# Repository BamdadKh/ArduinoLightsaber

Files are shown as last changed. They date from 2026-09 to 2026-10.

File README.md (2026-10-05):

# Arduino Lightsaber

A lightsaber prop built around an Arduino Nano on a custom PCB. It has a 144-LED blade,
sound from a DFPlayer Mini, swing detection with an MPU-6050, a small OLED and two buttons.
I built it for a Halloween costume.

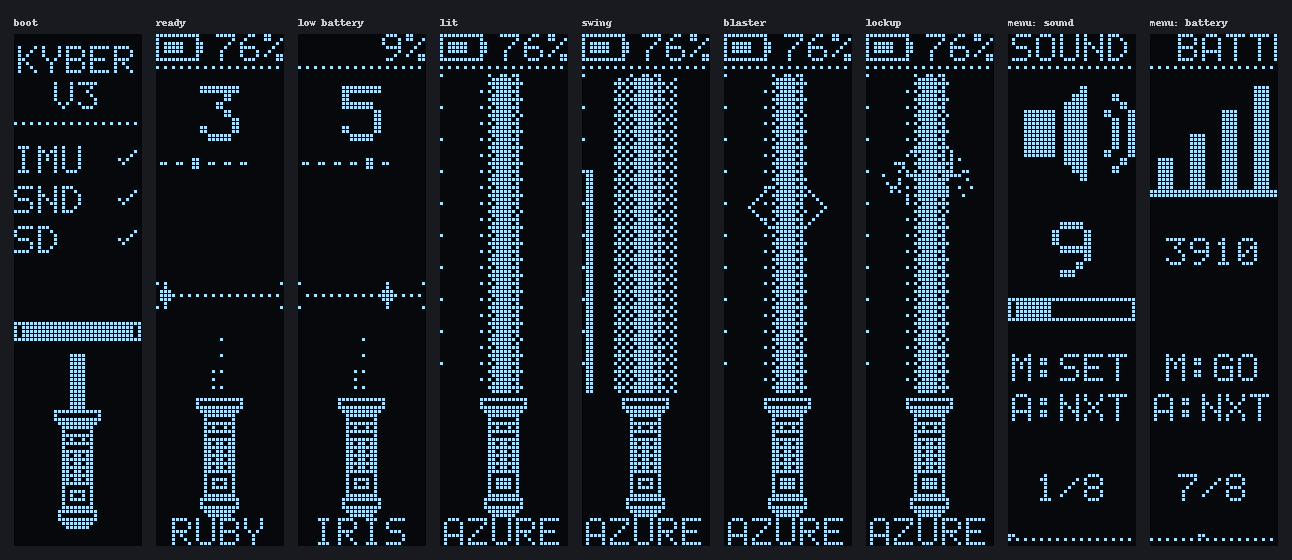
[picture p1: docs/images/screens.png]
OLED screens


*The OLED screens, rendered by the firmware's own UI code in a PC simulator.*

## Hardware

| | |
|---|---|
| Microcontroller | Arduino Nano (ATmega328P) |
| Motion | GY-521 (MPU-6050) on I²C |
| Sound | DFPlayer Mini, external amplifier and speaker |
| Blade | WS2812B strip, 144 LEDs, data on D6 |
| Buttons | main on D2, aux on D3 |
| Display | 0.91" SSD1306 128×32 OLED, software I²C on D8 (SDA) and D9 (SCL) |
| Power | one 18650 cell wired to the Nano's 5V pin, no boost converter |

The pin map, bill of materials and the known problems with the V3 board are in
[docs/hardware.md](docs/hardware.md). The schematic is in
[hardware/exports](hardware/exports/lightsaber-schematic.pdf). The schematic has mistakes the
board inherited; the firmware works around them, so trust the board and `docs/hardware.md`
over the schematic.

The hilt is modelled in Fusion 360 ([lightsaber-hilt.f3z](hardware/3d/lightsaber-hilt.f3z)),
and the printable tube is [hilt-tube.stl](hardware/3d/hilt-tube.stl), which GitHub shows in a
3D viewer.

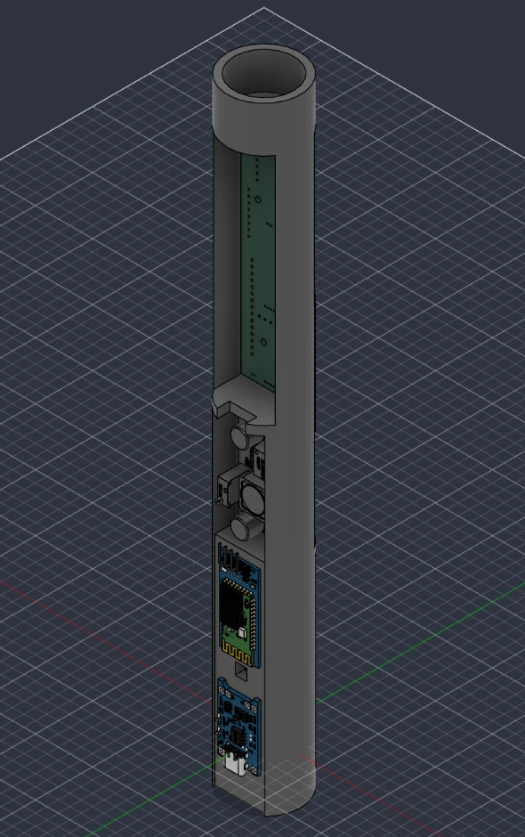
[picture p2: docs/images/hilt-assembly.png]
Hilt assembly


## Building

You need [arduino-cli](https://arduino.github.io/arduino-cli/) with the `arduino:avr` core.
The sketch has no third-party libraries.

```bash
arduino-cli compile -b arduino:avr:nano firmware/lightsaber
arduino-cli upload -b arduino:avr:nano -p COM3 firmware/lightsaber
```

Nano clones with the old bootloader need `arduino:avr:nano:cpu=atmega328old`. The build uses
about 18 KB of the 30 KB of flash and 42% of RAM. Pins, LED count, current limit and the
battery and motion thresholds are in [config.h](firmware/lightsaber/config.h).

Building with `-DDEBUG_SERIAL=1` prints swing speed and battery voltage over USB at 115200 baud:

```bash
arduino-cli compile -b arduino:avr:nano --build-property "compiler.cpp.extra_flags=-DDEBUG_SERIAL=1" firmware/lightsaber
```

### SD card

```bash
pip install numpy
python firmware/tools/build_sd_card.py
```

This fills `firmware/sd-card/` and writes `sound_lengths.h`. Copy the `MP3` and `ADVERT`
folders to the root of a FAT32 micro-SD card. Details and the track list are in
[firmware/sd-card/README.md](firmware/sd-card/README.md).

### First run

1. If the screen is upside down, flip it in the menu.
2. Lay the saber still and run CALIBRATE in the menu. This zeroes the gyro. It also happens
   at power-up if the saber is lying still.
3. Compare the BATTERY page with a multimeter on the cell. If it's off, scale `BANDGAP_MV`
   in `config.h`; the Nano's voltage reference is only accurate to about 10%.

## Controls

| Blade off | |
|---|---|
| MAIN click | Ignite |
| AUX click, double click | Next colour, previous colour |
| AUX hold | Open the menu |

| Blade on | |
|---|---|
| MAIN click | Retract |
| AUX click | Blaster block |
| AUX hold | Lockup, until released |
| Swing | Swing sound (automatic) |

| Menu | |
|---|---|
| AUX click, double click | Next page, previous page |
| MAIN click | Change the value or run the action |
| AUX hold | Save and exit |

The menu pages are sound, light, colour, sensitivity, flip, calibrate, battery and exit.
Light and colour preview on the blade. The saber retracts by itself after five minutes
without movement.

## How it works

The blade is rendered per pixel into the LED array, which is the only frame buffer in the
sketch. The OLED has none either. The panel is mounted on its side and driven in vertical
addressing mode, so one physical column is one 32-pixel row of the portrait screen. Each
screen is a function that returns a row as a `uint32_t`, and the UI streams a few rows per
`loop()` pass.

The LED strip needs interrupts off for about 4 ms per frame, which rules out serial
receive. The DFPlayer is therefore driven blind. The hum loops on the main channel,
effects play as DFPlayer adverts that pause and then resume it, and the one-shot lengths are
compiled in so the firmware can stop them when they end.

The cell feeds the Nano's supply directly, so the supply voltage is the cell voltage. The
firmware measures it against the internal 1.1 V reference. Charge level and warnings use the
voltage with the blade off, because the strip pulls it down by several tenths of a volt when lit.

| Module | Job |
|---|---|
| `saber.cpp` | modes and controls |
| `imu.cpp` | MPU-6050 reading and swing detection |
| `blade.cpp` | blade colours, ignition and effects |
| `color.cpp` | WS2812B driver, current limit |
| `ui.cpp`, `gfx.h`, `oled.cpp` | OLED screens and display driver |
| `audio.cpp` | DFPlayer protocol and sound playback |
| `buttons.cpp` | debouncing, clicks, holds |
| `power.cpp` | battery voltage |
| `settings.cpp` | EEPROM settings, colour table |

## Repository

```
firmware/lightsaber/   the sketch
firmware/sd-card/      sounds for the DFPlayer
firmware/tools/        asset and SD card builders, PC simulator
hardware/kicad/        KiCad 8 project
hardware/fabrication/  gerbers exactly as ordered (V3)
hardware/exports/      schematic PDF, PCB renders
hardware/3d/           hilt model, tube STL, PCB STEP
docs/                  hardware notes, images
```

The simulator runs the real `ui.cpp` and `blade.cpp` on a PC (it needs MSYS2 g++ or MSVC):

```bash
python firmware/tools/sim/run_sim.py
python firmware/tools/make_readme_images.py
```

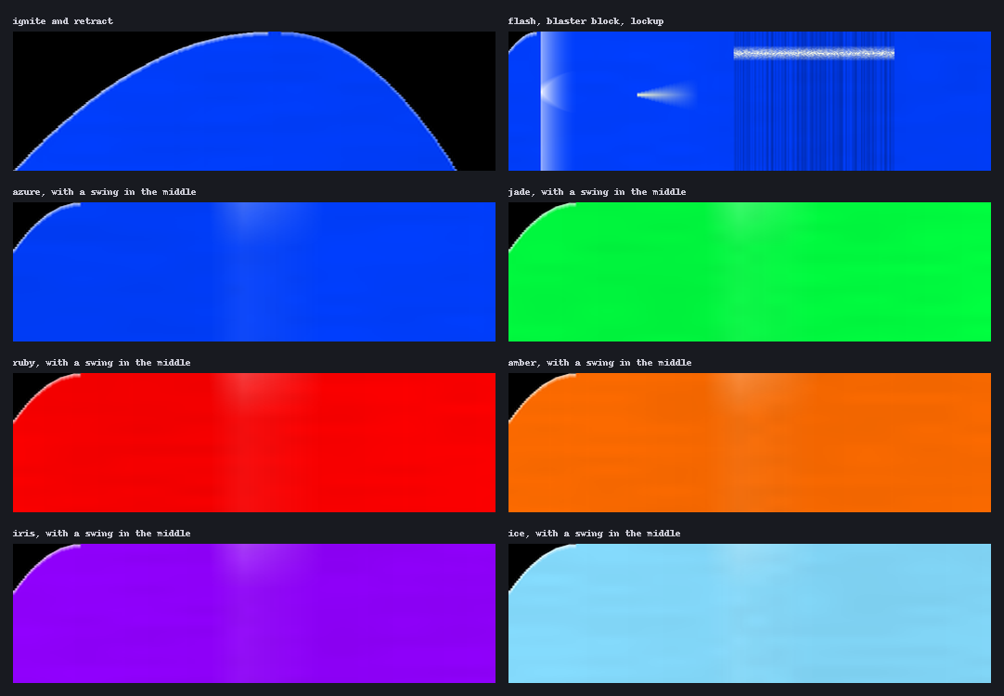
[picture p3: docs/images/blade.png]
Blade simulation


*Blade timelines from the simulator. Time runs left to right and the hilt is at the bottom.*

## Credits

The blade sounds come from the TeensySF font in the
[ProffieOS](https://fredrik.hubbe.net/lightsaber/) default SD card, by Fredrik Hubinette
([CC BY-SA 4.0](https://creativecommons.org/licenses/by-sa/4.0/)). The menu and boot sounds
are synthesized by the repository's tools.

## License

[MIT](LICENSE). The sound files are under their own licence, see above.

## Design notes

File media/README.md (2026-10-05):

# Media

`videos/` holds demo and build videos (`.mp4`, `.mov`), tracked with Git LFS. `photos/` holds
build and finished-hilt photos.

Name files `YYYY-MM-DD-short-description.ext`, for example `2025-10-30-first-ignite.mp4`.

GitHub won't play LFS videos inline. To show one in the README, drag it into an issue or PR
comment to get a `user-attachments` URL, or link a YouTube video.

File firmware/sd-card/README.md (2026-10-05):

# SD card

`MP3/` and `ADVERT/` go in the root of a FAT32 micro-SD card. The DFPlayer finds files in these
folders by number, so copy order doesn't matter. `build_sd_card.py` fills both (see the main
README); the files are committed so a clone is ready to copy.

```
MP3/      main channel: hum loop, ignite, retract, lockup loop, menu sounds
ADVERT/   short sounds played over the hum: swings, clashes, blaster blocks
```

The hum loops on the main channel. Every short effect is a DFPlayer advert, which pauses the
hum, plays, and lets it carry on. That is how one decoder layers sound without a BUSY pin.

The blade sounds are from the TeensySF font in the ProffieOS default SD card, by Fredrik
Hubinette, [CC BY-SA 4.0](https://creativecommons.org/licenses/by-sa/4.0/). The menu and boot
sounds are synthesized by `make_ui_sounds.py`.

## Tracks

`MP3/`

| File | Sound | Notes |
|---|---|---|
| 0001 | boot chime | plays once at power-up |
| 0002 | hum | looped |
| 0003 | ignite | plays once, then the hum starts |
| 0004 | retract | plays once |
| 0005 | lockup | looped while AUX is held |
| 0006 | menu tick | |
| 0007 | menu confirm | |
| 0008 | menu back | |
| 0009 | low battery | |

`ADVERT/`

| Files | Sound |
|---|---|
| 0001-0004 | slow swings, picked at random, never the same twice in a row |
| 0005-0008 | fast swings (peak above `SWING_FAST_DPS`) |
| 0009-0012 | clashes, played when a lockup ends |
| 0013-0016 | blaster blocks |
| 0017 | menu tick while the blade is lit |
| 0018 | colour change |

## Using your own sounds

- WAV or MP3, mono, 16-bit, 22.05 to 44.1 kHz. Keep the four-digit number and the extension. If
  a DFPlayer clone refuses WAV, convert with `ffmpeg -i 0002.wav -q:a 2 0002.mp3`.
- Loops (hum, lockup) should be cut at a zero crossing so they repeat without a click. MP3
  encoders add a few milliseconds of padding, so WAV loops are cleaner.
- Without a BUSY pin the firmware can't hear when a sound ends. It stops each one-shot by its
  length, which lives in `firmware/lightsaber/sound_lengths.h` (written by `build_sd_card.py`).
  Trim silence off the end of one-shots, or the hum will start late.

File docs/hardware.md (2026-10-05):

# Hardware

The fabricated V3 PCB (`hardware/fabrication/lightsaber-v3-gerbers.zip`) and the firmware are
the source of truth. The KiCad schematic has mistakes that were worked around in code after the
boards were ordered, so don't trust it over the board.

## Bill of materials

| Ref | Part | Notes |
|-----|---|---|
| A1 | Arduino Nano v3 (ATmega328P) | Socketed on 2×15 headers |
| U1 | GY-521 (MPU-6050) | I²C, address `0x68`; gyro + accel (±2000 °/s, ±16 g) |
| U2 | DFRobot DFPlayer Mini (DFR0299) | micro-SD with sound files, see [`firmware/sd-card`](../firmware/sd-card/README.md) |
| J1 | WS2812B strip, 144 LEDs | 3-pin header: GND / data / 5V |
| J2 | Momentary push button (main) | To GND, internal pull-up |
| J4 | Momentary push button (aux) | To GND, internal pull-up |
| J3 | **SSD1306 OLED** (as built) | The schematic calls this header Bluetooth (D8/D9), but the OLED is wired here and runs on software I²C. SDA to D8 (white), SCL to D9 (yellow) |
| J5 | Intended for the OLED (I²C on A4/A5) | Unused as built |
| J7 | Speaker/amp header | DFPlayer `DAC_R`, 5V and GND, to an external amp |
| J6 | 5V / GND power in | |
| J8 | Battery sense | Not routed on the PCB, and not needed (see known issues) |
|  | 4× M2 mounting holes | 2.2 mm |

## Pin map (as built)

| Nano pin | Net | Connected to | Firmware |
|---|-----|---|---|
| D2  | `d2`  | J2 main button | `PIN_BTN_MAIN` |
| D3  | `d3`  | J4 aux button | `PIN_BTN_AUX` |
| D6  | `d6`  | J1 WS2812B data | `PIN_LED` |
| D8  | `d8`  | J3, OLED SDA (white) | software I²C (`oled.cpp`, PB0) |
| D9  | `d9`  | J3, OLED SCL (yellow) | software I²C (`oled.cpp`, PB1) |
| D10 | | DFPlayer TX | polled once at boot to detect the player (`audio.cpp`, PB2) |
| D11 | | DFPlayer RX | bit-banged 9600 baud TX (`audio.cpp`, PB3) |
| A4  | `sda` | MPU-6050 (+ J5, unused) | I²C |
| A5  | `scl` | MPU-6050 (+ J5, unused) | I²C |
| A7  | `a7`  | J8 battery sense | unused |

## Known issues

Found by comparing the firmware, schematic and PCB, and by running DRC.

What checks out:
- Every routed pin the firmware uses (D2, D3, D6, D10, D11, A4, A5) matches both the schematic and the PCB.
- The Nano, DFPlayer and GY-521 footprints have pads in the same physical order as the real modules.
- The 5V and GND nets are copper pours, not thin traces.

Board issues:
- **A7 battery sense is not routed, and the firmware doesn't need it.** With the cell wired
  straight to the Nano's 5V pin, Vcc *is* the cell voltage, so the firmware measures Vcc
  against the internal 1.1 V bandgap. No bodge wire. The bandgap is only good to about
  +-10 %: check the menu > BATTERY millivolts against a multimeter once and scale
  `BANDGAP_MV` in `config.h` if they differ. The percentage and low-battery warning use the
  cell's *resting* voltage (blade off); the lit-blade sag is ignored except as a brown-out guard.
- **DFPlayer BUSY (pin 16) is not connected.** The firmware is built around this: the hum is
  looped by the player itself, effects are "adverts" that resume it, and one-shot lengths come
  from `sound_lengths.h`.
- **The DFPlayer's built-in amp is unused.** SPK1/SPK2 aren't connected. Audio leaves through
  `DAC_R` (right channel only) on J7, so an external amplifier is required.
- **No 1 kΩ series resistor** between Nano TX and DFPlayer RX. DFRobot recommends one to reduce noise and hiss.
- **Wire holes are too small.** J1, J2, J4, J6, J7 and J8 use 1.00 mm pitch header footprints with
  **0.5 mm drills**, and J3 and J5 use 1.27 mm pitch with 0.65 mm drills. Only thin solid-core
  wire fits (roughly 24 AWG or smaller). That's a problem for J1 and J6, which carry the LED
  strip's power, since the strip can pull several amps.
- **The OLED is on D8/D9, not the hardware I²C bus.** It's wired to J3, the header the schematic
  labels for Bluetooth, so it has to run on software I²C and can't share the MPU-6050's A4/A5 bus.
  Wire OLED SDA to D8 and SCL to D9. Go by the pin labels on the OLED, not the wire colours.
- **The power system isn't in the schematic or PCB.** The board only has a `5V/G` input (J6) and a
  `bat+` pad (J8). The battery, charging, switch and 5V regulation all live off the board and
  aren't documented here.
- **No LED current limit in hardware.** 144 WS2812B LEDs at full white draw about 8.6 A.
  The firmware estimates each frame's current and scales it down to `LED_MAX_MA` (3.2 A by default;
  set it to what your cell can deliver). Even when dark the strip idles at roughly 1 mA per LED,
  so use the hilt's power switch for storage.
- DRC on the PCB file reports 47 violations: 25 isolated copper, 7 clearance, 7 courtyard overlap, and minor silk issues.
- `fp-lib-table` points to a `DFR0299.pretty` in the author's Downloads folder, which no longer exists.
  The board still opens because its footprints are stored inside the `.kicad_pcb`.

## Hilt / 3D model

| File | What it is |
|---|---|
| `hardware/3d/lightsaber-hilt.f3z` | Fusion 360 archive of the hilt assembly (editable source, Git LFS) |
| `hardware/3d/hilt-tube.stl` | Printable hilt tube mesh; GitHub renders it in a 3D viewer |
| `hardware/3d/lightsaber-pcb.step` | STEP of the assembled PCB, exported from KiCad |

The hilt is a tube with a cut-away channel. The PCB sits in the upper section and the
off-board modules stack below it. Components placed in the assembly:

| Component | Role |
|---|---|
| Lightsaber PCB (V3) | Main board, see above |
| 18650 battery holder | Single-cell Li-ion supply |
| TP4056 charging module | USB-C charging for the 18650 |
| DC-DC XL6009 | Boost from cell voltage to 5 V |
| PAM8403 3 W amplifier | External amp fed from J7 (`DAC_R`) |
| Flat speaker (35×25) | |
| 2× tactile push button (B3F) | Main (J2) and aux (J4) buttons |
| OLED 0.91" SSD1306 128×32 | Status display on J3, mounted along the hilt |
| HC-06 Bluetooth module | Placeholder. Bluetooth is shelved and J3 is used by the OLED |

To update the model, export a fresh `.f3z` from Fusion (File > Export > Fusion Archive) over
the existing file. Use `.f3z` rather than `.f3d` so the linked component models come along.
Re-export the tube with right-click on the body > Save As Mesh > STL to `hilt-tube.stl`.

## Regenerating exports

KiCad 8 CLI (`C:\Program Files\KiCad\8.0\bin\kicad-cli.exe`):

```bash
kicad-cli sch export pdf -o hardware/exports/lightsaber-schematic.pdf hardware/kicad/lightsaber.kicad_sch
kicad-cli sch export svg -o hardware/exports hardware/kicad/lightsaber.kicad_sch
kicad-cli pcb export svg --layers F.Cu,F.Silkscreen,Edge.Cuts --page-size-mode 2 --exclude-drawing-sheet -o hardware/exports/lightsaber-pcb-front.svg hardware/kicad/lightsaber.kicad_pcb
kicad-cli pcb export svg --layers B.Cu,B.Silkscreen,Edge.Cuts --mirror --page-size-mode 2 --exclude-drawing-sheet -o hardware/exports/lightsaber-pcb-back.svg hardware/kicad/lightsaber.kicad_pcb
```

Don't regenerate `lightsaber-v3-gerbers.zip`. It is the exact file sent to the fab.

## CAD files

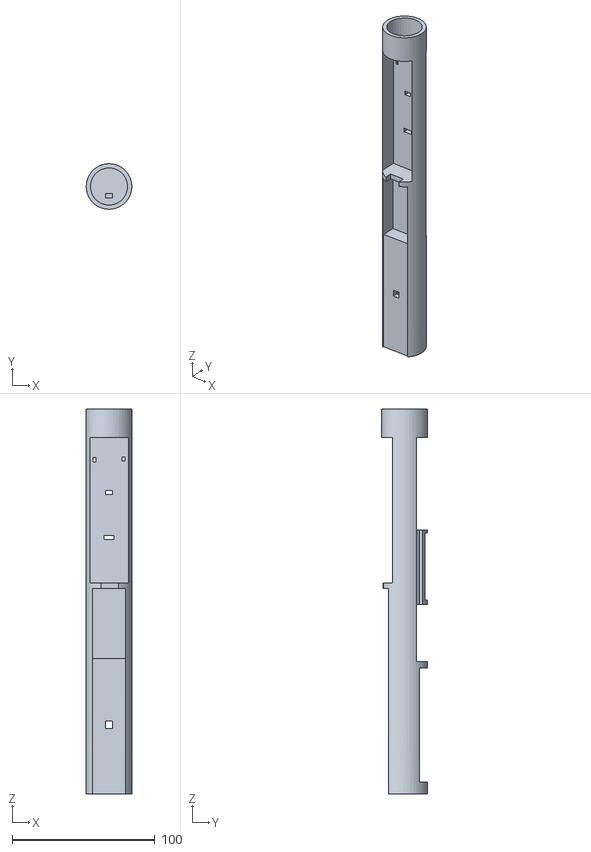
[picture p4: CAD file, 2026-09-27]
hardware/3d/hilt-tube.stl
32.0 x 32.0 x 270.0

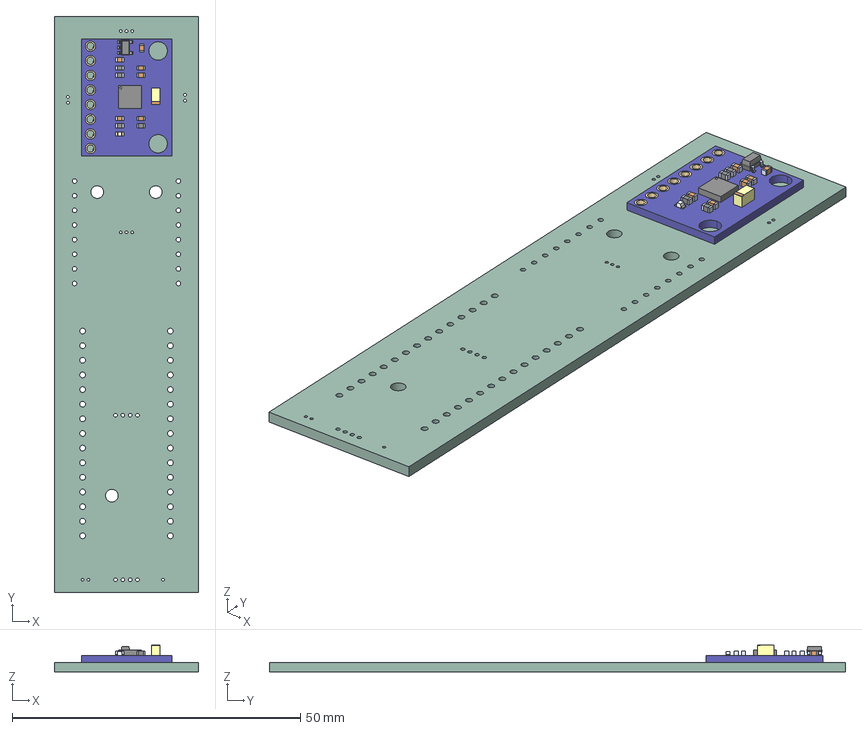
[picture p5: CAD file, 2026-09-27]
hardware/3d/lightsaber-pcb.step
25.0 x 100.0 x 4.65 mm
GY-521
_autosave-LightsberV3_PCB

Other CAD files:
hardware/3d/lightsaber-hilt.f3z

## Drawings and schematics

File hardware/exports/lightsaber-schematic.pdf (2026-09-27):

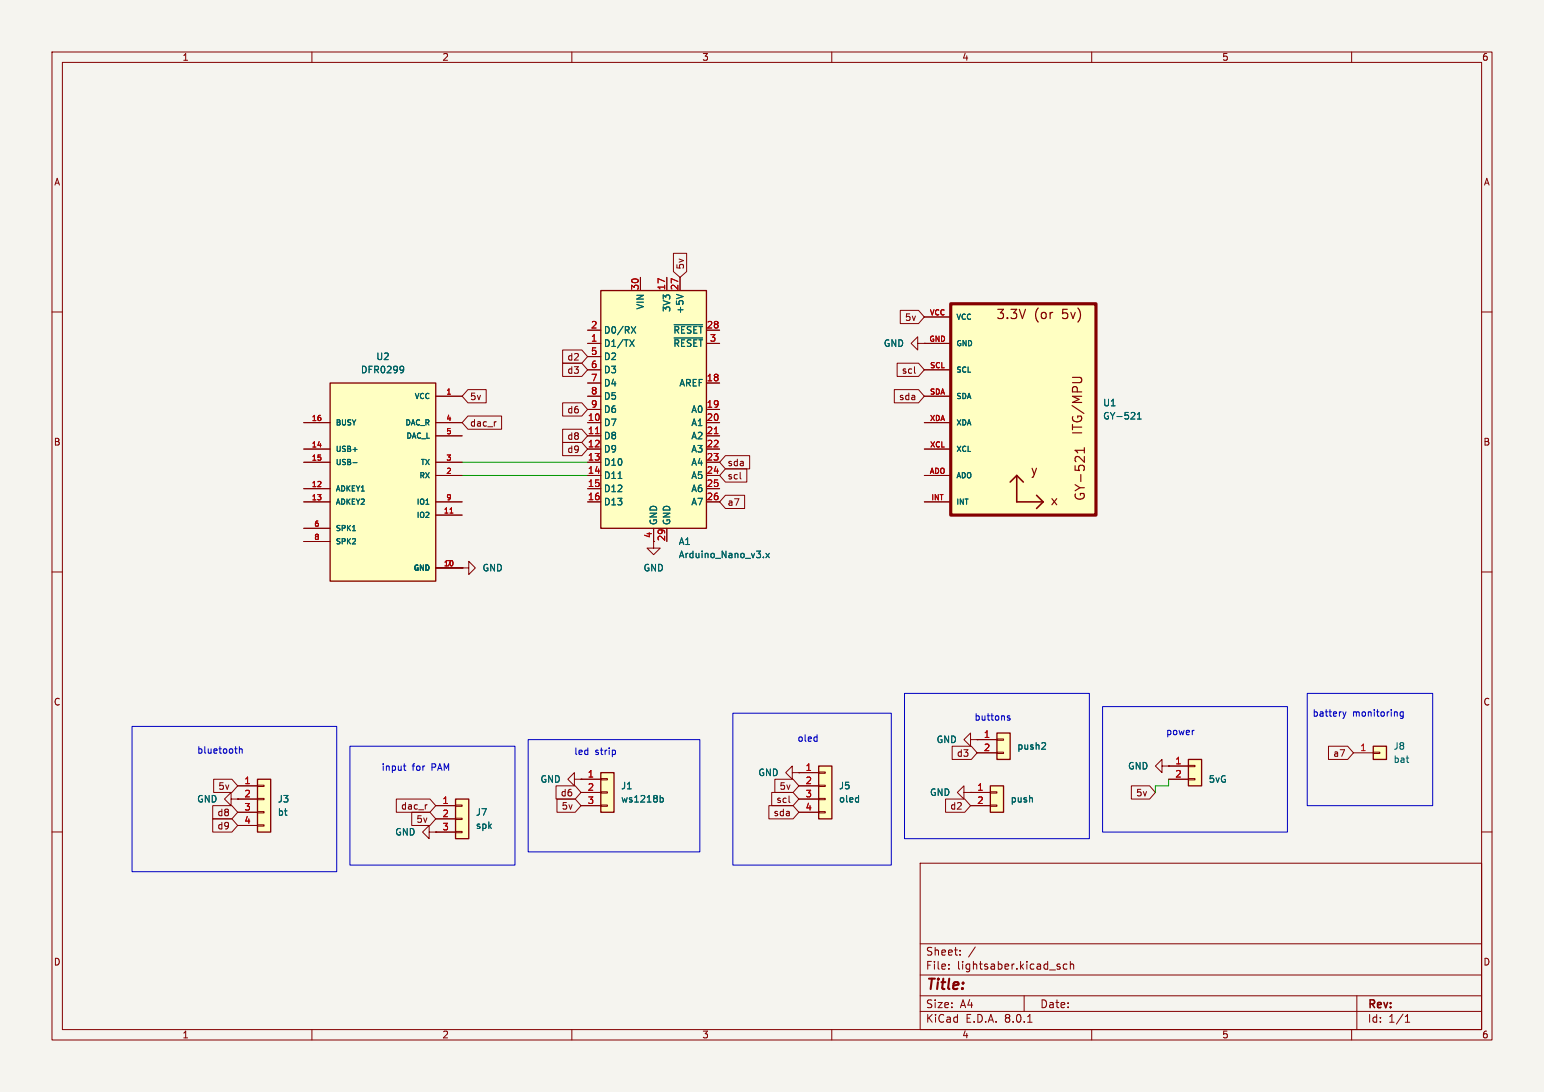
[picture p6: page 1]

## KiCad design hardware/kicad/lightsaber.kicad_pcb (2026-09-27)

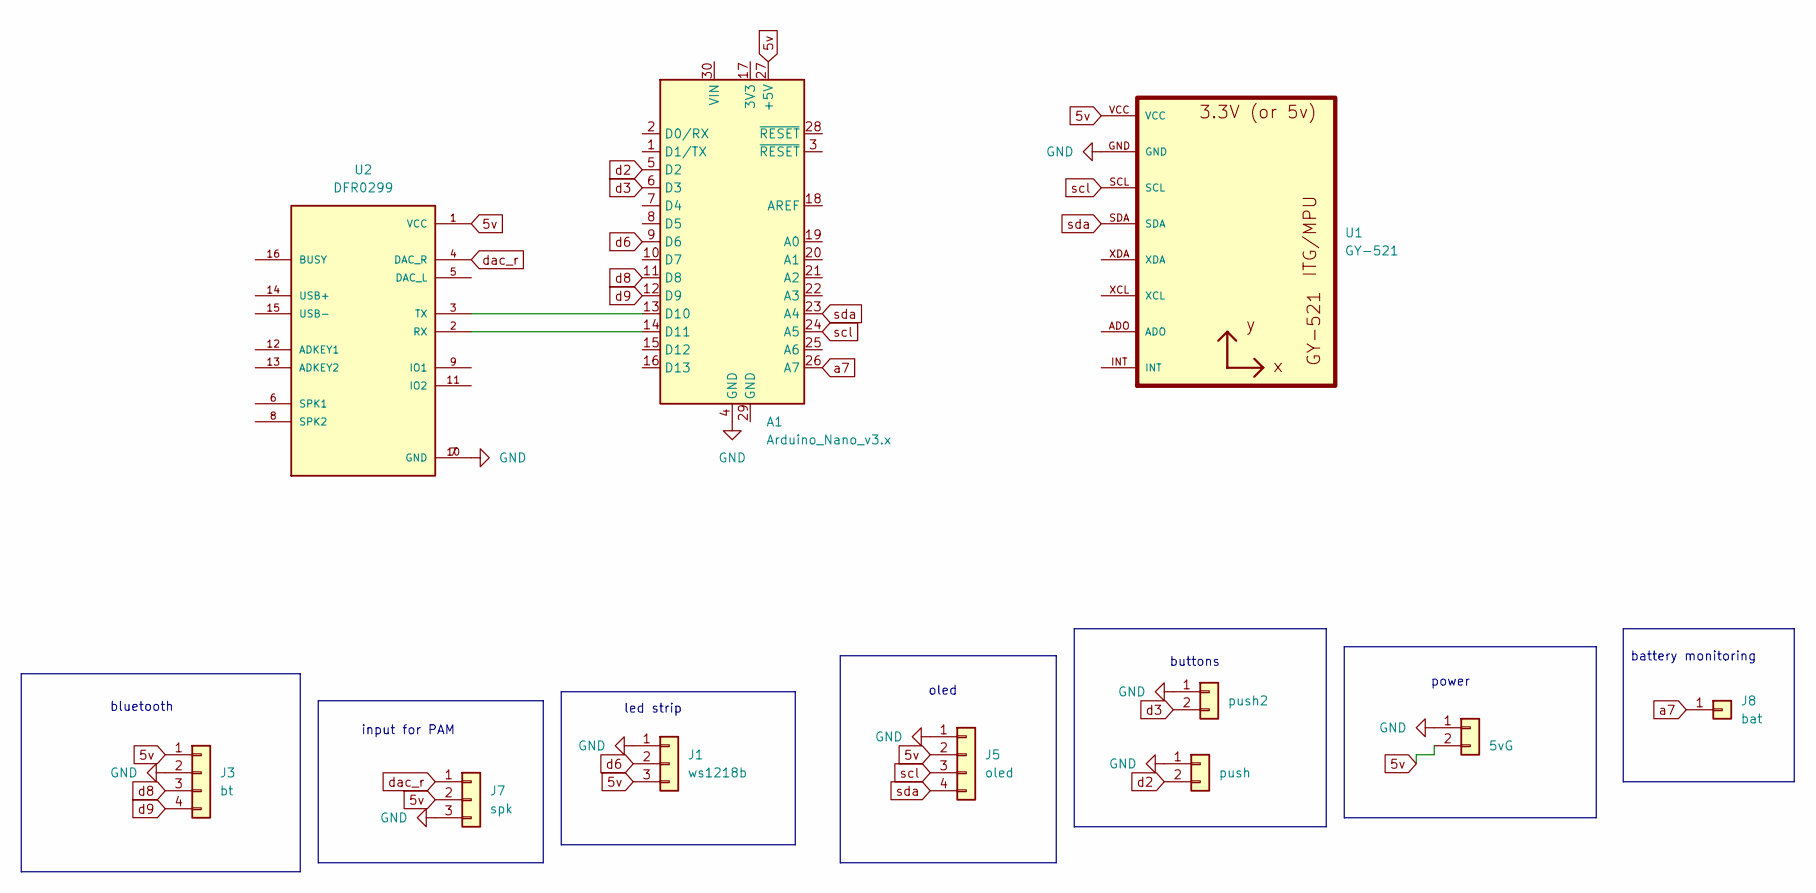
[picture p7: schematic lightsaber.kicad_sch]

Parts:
A1: Arduino_Nano_v3.x; Arduino_Nano
J1: ws1218b; PinHeader_1x03_P1.00mm_Vertical
J2: push; PinHeader_1x02_P1.00mm_Vertical
J3: bt; PinHeader_1x04_P1.27mm_Vertical
J4: push2; PinHeader_1x02_P1.00mm_Vertical
J5: oled; PinHeader_1x04_P1.27mm_Vertical
J6: 5vG; PinHeader_1x02_P1.00mm_Vertical
J7: spk; PinHeader_1x03_P1.00mm_Vertical
J8: bat; PinHeader_1x01_P1.00mm_Vertical
U1: GY-521
U2: DFR0299; MODULE_DFR0299

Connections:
5v: A1.27 (+5V), J1.3, J3.1, J5.2 (vcc), J6.2 (5v), J7.2, U1.VCC, U2.1 (VCC)
GND: A1.4 (GND), J1.1, J2.1 (G), J3.2, J4.1 (G), J5.1 (gnd), J6.1 (G), J7.3, U1.GND, U2.7 (GND), U2.10 (GND)
unnamed: A1.13 (D10), U2.3 (TX)
unnamed: A1.14 (D11), U2.2 (RX)
a7: A1.26 (A7), J8.1
d2: A1.5 (D2), J2.2 (dat)
d3: A1.6 (D3), J4.2 (dat)
d6: A1.9 (D6), J1.2
d8: A1.11 (D8), J3.3
d9: A1.12 (D9), J3.4
dac_r: J7.1, U2.4 (DAC_R)
scl: A1.24 (A5), J5.3 (sck), U1.SCL
sda: A1.23 (A4), J5.4 (sda), U1.SDA

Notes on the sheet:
bluetooth
input for PAM
power
led strip
buttons
oled
battery monitoring

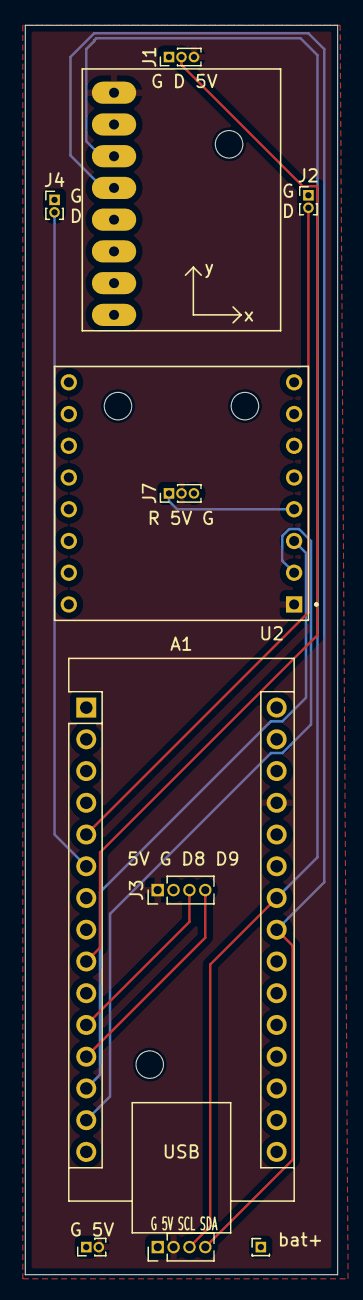
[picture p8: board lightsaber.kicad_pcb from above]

Board: 2 copper layers, 25.0 x 100.0 mm, 11 parts (0 on the bottom side), 13 nets.

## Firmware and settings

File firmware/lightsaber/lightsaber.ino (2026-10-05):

/*
  Arduino Nano lightsaber firmware

  Hardware (V3 PCB): Nano, MPU-6050 (A4/A5), DFPlayer Mini (D10/D11), 144 x WS2812B (D6),
  main button D2, aux button D3, 128x32 SSD1306 on D8/D9 mounted portrait. The cell feeds
  the 5V pin directly; its voltage is read as Vcc.

  Module map
    saber.cpp    modes and controls
    imu.cpp      MPU-6050: swing detection
    blade.cpp    LED blade look, ignition, effect overlays
    ui.cpp       portrait OLED screens, streamed as scanlines (no framebuffer)
    audio.cpp    DFPlayer: looping hum + advert overlays, TX-only bit-bang serial
    buttons.cpp  two buttons: clicks and holds
    power.cpp    battery voltage (Vcc against the internal bandgap)
    settings.cpp EEPROM settings and the colour table

  Every loop() pass does a slice of each job. Nothing blocks for longer than one LED
  frame (~4.5 ms) or one DFPlayer command (~10 ms).
*/
#include "config.h"
#include "state.h"
#include "settings.h"
#include "twi.h"
#include "imu.h"
#include "audio.h"
#include "blade.h"
#include "buttons.h"
#include "power.h"
#include "ui.h"
#include "saber.h"

#if DEBUG_SERIAL
// Telemetry to the USB serial port (115200 8N1) without HardwareSerial's ~1.7 KB:
// a TX-only bit-bang on D1, one line every 250 ms:
// L loops/s, M mode, S swing dps, B battery mV (rested cell; see power.cpp)
#define DBG_BIT (F_CPU / 115200)
static void dbgByte(uint8_t b) {
  uint8_t sreg = SREG;
  cli();
  PORTD &= ~_BV(1);
  __builtin_avr_delay_cycles(DBG_BIT - 4);
  for (uint8_t i = 0; i < 8; i++) {
    if (b & 1) PORTD |= _BV(1);
    else PORTD &= ~_BV(1);
    b >>= 1;
    __builtin_avr_delay_cycles(DBG_BIT - 9);
  }
  PORTD |= _BV(1);
  __builtin_avr_delay_cycles(DBG_BIT);
  SREG = sreg;
}
static void dbgStr(const char* p) {
  while (uint8_t c = pgm_read_byte(p++)) dbgByte(c);
}
static void dbgNum(const char* label, int16_t v) {
  dbgStr(label);
  if (v < 0) {
    dbgByte('-');
    v = -v;
  }
  char b[6];
  uint8_t n = 0;
  do b[n++] = '0' + v % 10; while (v /= 10);
  while (n) dbgByte(b[--n]);
  dbgByte(' ');
}
static void debugPrint(uint32_t now) {
  static uint32_t last;
  static uint16_t loops;
  loops++;
  if (now - last < 250) return;
  last = now;
  dbgNum(PSTR("L="), loops * 4);
  dbgNum(PSTR("M="), sys.mode);
  dbgNum(PSTR("S="), motion.swingDps);
  dbgNum(PSTR("B="), sys.battMv);
  dbgByte(13); // CR LF
  dbgByte(10);
  loops = 0;
}
#endif

void setup() {
#if DEBUG_SERIAL
  PORTD |= _BV(1);
  DDRD |= _BV(1);
#endif
  settingsLoad();
  buttonsInit();
  audioInit();
  bladeInit();
  bladeSetBrightness(cfg.bright);
  uiInit();
  twiInit();
  sys.imuOk = imuInit();
  if (sys.imuOk) imuCalibrateBias(false); // only takes if the saber is lying still
  powerInit();
  saberInit(millis());
}

void loop() {
  uint32_t now = millis();
  sys.now = now;
  buttonsUpdate(now);

  if (sys.imuOk) imuUpdate(now);

  saberUpdate(now);
  audioUpdate(now);
  powerUpdate(now);
  if (bladeRender(now)) ledShow(leds, NUM_LEDS, bladeBrightness(), LED_MAX_MA);
  uiPump(now);
  settingsUpdate(now);

#if DEBUG_SERIAL
  debugPrint(now);
#endif
}

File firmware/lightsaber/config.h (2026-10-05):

// Build-time configuration. Everything a user might want to tune lives here;
// runtime settings (volume, brightness, colour...) are in the on-saber menu.
#pragma once

// ---------------------------------------------------------------- pins (V3 PCB, as built)
#define PIN_BTN_MAIN 2   // J2, INT0
#define PIN_BTN_AUX  3   // J4, INT1
#define PIN_LED      6   // J1 WS2812B data
// Fixed by the drivers (direct port access, change there too if you move them):
//   OLED  SDA = D8 (PB0), SCL = D9 (PB1)          (oled.cpp)
//   DFPlayer  RX on D11 (PB3), TX on D10 (PB2)     (audio.cpp)
//   MPU-6050 on hardware I2C A4/A5                 (twi.cpp)

// ---------------------------------------------------------------- blade
#define NUM_LEDS        144   // must stay <= 255 (uint8_t indices)
#define LED_MAX_MA      3200  // strip current budget. A solid blue blade is ~2.9 A at full
                              // brightness; lower this if the cell or its protection trips
#define BLADE_FPS_CAP   125   // frames per second ceiling for the strip

// ---------------------------------------------------------------- battery
// The cell feeds the Nano's 5V pin directly, so the Nano's own supply IS the cell: power.cpp
// measures Vcc against the internal 1.1 V bandgap and needs no sense wire. The bandgap is
// only good to +-10 % chip to chip; if the readout is off, measure the cell with a multimeter
// and scale this (new = old * true_mV / shown_mV). Menu > BATT shows the raw millivolts.
#define BANDGAP_MV      1100
#define BATT_LOW_MV     3500  // rested cell below this: warn once (clears above BATT_LOW_MV + 100)
#define BATT_EMPTY_MV   3300  // rested cell below this: lock the blade out
#define BATT_SAG_MV     3000  // blade on and the cell *under load* below this for a while: shut down
#define BATT_USB_MV     4300  // above this we're on USB (reads ~4.4 V), not the cell (max 4.2 V)

// ---------------------------------------------------------------- sound font timing
// Lengths of the non-looping main-channel tracks, in ms. make_sounds.py writes
// sound_lengths.h with the exact values for the bundled font; if you use your own
// font, edit that file (or override here).
#include "sound_lengths.h"
#define AUDIO_CMD_GAP_MS 45   // DFPlayer needs breathing room between commands

// ---------------------------------------------------------------- motion (defaults; menu scales them)
#define SWING_START_DPS   230  // gyro speed that counts as a swing (sensitivity 5)
#define SWING_END_DPS     110
#define SWING_FAST_DPS    620  // peak above this picks the fast swing bank
#define SWING_GAP_MS      700  // minimum time between swing sounds (the clips run up to ~0.9 s)
#define MOTION_DPS        18   // anything above is "the saber is being handled"

// ---------------------------------------------------------------- timing
#define IDLE_OFF_MS       (5UL * 60 * 1000) // blade on but untouched: auto retract
#define MENU_TIMEOUT_MS   30000
#define SETTINGS_SAVE_MS  2500             // EEPROM write is deferred this long after a change

// ---------------------------------------------------------------- debug
#ifndef DEBUG_SERIAL
#define DEBUG_SERIAL 0  // 1: 115200 baud telemetry
#endif

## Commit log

2026-09-27 Reorganize repo into firmware, hardware, docs and media
    - Move sketch to firmware/lightsaber, KiCad project to hardware/kicad
    (fix "Lightsber" typo), gerber zip to hardware/fabrication, STEP to hardware/3d
    - Add schematic PDF/SVG and PCB front/back SVG exports
    - Drop loose gerbers (identical to the zip), KiCad backups and cache
    - Add hardware reference with BOM, as-built pin map and known board issues
    - Rewrite README, add SD card layout notes, media folders, MIT license
    [lightsaber-pcb.step, lightsaber.kicad_pcb, lightsaber.kicad_sch]
2026-09-27 Add Fusion 360 hilt assembly
    Track the hilt as a Fusion archive (.f3z) via Git LFS, add an assembly
    screenshot, and document the 3D files and modelled components in the
    README and docs/hardware.md.
    [lightsaber-hilt.f3z]
2026-09-27 Add printable hilt tube STL
    GitHub renders STL files in an interactive 3D viewer, so the mesh stays
    out of LFS and is linked from the README.
    [hilt-tube.stl]
2026-09-27 Add OLED status display
    Show the current state and blade colour on the 0.91" 128x32 SSD1306 on
    J3 (software I2C on D8/D9), with text running along the hilt.
    U8x8's built-in software I2C blocked for ~437 ms per redraw, so the
    sketch uses its own direct-port bit-bang driver (~0.65 ms per character)
    and draws one character per loop pass, including during the ignite and
    retract animations. The blade-off states are now paced with millis()
    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
2026-09-28 Rewrite firmware as KYBER OS 2
    Replace the single-sketch firmware with a modular, non-blocking one that uses
    all the V3 hardware: both buttons, gyro + accel motion, the portrait OLED and
    battery sense on A7.
    - Drop FastLED, OneButton, DFRobotDFPlayerMini, U8g2 and Wire for in-tree
    drivers (WS2812 loop, OLED scanline streaming, TX-only DFPlayer serial, TWI).
    Flash 30.3/30.7 KB, RAM 54% (was 81%).
    - Blade: 8 styles, 4 ignition/retraction animations, blaster, clash, stab,
    force, lockup, drag, melt and lightning effects, swing-reactive animation.
    - Motion: swing accents, clash, stab, twist gestures, pitch, axis calibration.
    - Sound: looping hum with advert overlays (no BUSY pin needed), h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
    [audio.cpp, color.cpp]
2026-10-05 Simplify firmware: fix battery warnings, one blade look, real saber sounds
    Firmware
    - Battery: read Vcc (the cell feeds the 5V pin directly) instead of A7. Percentage and
    warnings use the resting voltage, so the sag from a lit blade no longer triggers a
    low-battery warning on every ignition. One warning per low spell, lockout only when
    really empty, brown-out guard under load, USB detected.
    - Cut features to a focused set: no training game, HUD, colour wheel, gestures, sleep,
    stats, reset, extra styles/ignitions, stab/lightning/melt/drag/force effects, or clash
    detection. Controls: MAIN ignite/retract, AUX blaster/lockup/colour/menu.
    - One blade look (saturated, shimmer, breathing)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
    [audio.cpp, color.cpp, config.h]
2026-10-05 Clean up code and docs
    - Remove dead code: unused button chord/long/press events, unused audio, blade and OLED
    functions, unused sound tracks and menu icons.
    - Renumber the SD card tracks without the removed sounds. Replace make_sounds.py and
    get_saber_sounds.py with build_sd_card.py (plus make_ui_sounds.py for the menu sounds).
    - Rewrite the README in plainer language, drop the status and TODO sections, and rename the
    README images so GitHub does not serve cached copies. Regenerate them.
    - Remove emoji, em dashes and arrows from docs and comments. Drop the stale state-machine image.
    The SD card contents changed (tracks renumbered): flash the firmware and copy the card together.
    [audio.cpp]
